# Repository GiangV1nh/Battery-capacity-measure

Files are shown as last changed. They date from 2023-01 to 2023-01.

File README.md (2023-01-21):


# 1. Giới thiệu
Mạch này đo dung lượng một cell Li-Ion hoặc nhiều cell Li-Ion mắc song song hoặc các loại pin khác có điện áp tối đa dưới 5.5V. Đơn vị dung lượng đo được là mAh.
# 2. Thông số kỹ thuật
- Điện áp nguồn cấp: 9V đến 15V.
- Điện áp pin đo được: 0V đến 5.5V.
- Dòng xả tối đa: 2A.
- Mức điều chỉnh dòng xả tối thiểu: 0.02A.
- EODV: 0V đến 4.2V.
- Mức điều chỉnh EODV tối thiểu: 0.02V.
- Dung lượng tối đa đo đươc: 99,999mAh.
# 3. Hướng dẫn sử dụng
Giao diện hiện thị trên LCD như sau:
|Hình 1 |
| :---: |
| |

Dòng xả và EODV là hai thông số điều chỉnh được. Bên cạnh có dấu *, biểu thị hiện đang điều chỉnh thông số nào. Dấu * ở vị trí nào thì khi vặn encoder sẽ điều chỉnh thông số tại vị trí đó. Để thay đổi vị trí dấu * thì nhấn nhả encoder. Điện áp pin là điện
áp đo được từ pin đang gắn vào mạch. Dung lượng pin tăng dần trong quá trình xác định. Sau khi đặt các thông số dòng xả và EODV, nhấn và giữ encoder trong hai giây
thì mạch bắt đầu xả pin, dấu * biến mất và LED báo hiệu trên mạch sáng. Trong quá trình xả, nhấn nhả encoder thì ngưng xả.

Chuẩn bị cell pin cần đo dung lượng, nạp đầy cell này và lắp vào mạch theo đúng cực tính. Không được lắp ngược lại vì làm cho diode trong MOSFET dẫn, có dòng xả lớn qua mạch gây hỏng. Tiến hành đặt dòng xả và áp EODV, sau đó nhấn và giữ encoder trong hai giây, dấu * biến mất và LED D1 sáng, báo hiệu đang xả pin. Trong quá trình xả, dung lượng pin hiển thị tăng dần. Khi điện áp pin xuống đến ngưỡng EODV, mạch ngưng xả, dung lượng pin được hiển thị trên LCD. Khi đo pin khác hoặc đo lại, cần phải reset mạch cho dung lượng hiển thị trên LCD bằng 0mAh.
Nếu không có pin (điện áp đo được 0V) hoặc điện áp pin thấp hơn hoặc bằng EODV hoặc dòng xả là 0A thì mạch không xả. Trong quá trình xả pin, nếu ngắt pin ra thì mạch tự ngừng xả và ngừng xác định dung lượng.

# Lưu ý
- Không gắn pin ngược cực.
- Không xả pin dưới mức EODV của loại pin đang cần xác định vì như thế sẽ làm hỏng pin.
# 4. Cách chỉnh mạch cho lần đầu dùng
Chuẩn bị nguồn có khả năng cấp dòng lớn hơn 2A. Nếu điện áp nguồn nhỏ hơn 5.5V thì cắm J3 như hình sau:
|Hình 2 |
| :---: |
| |

Nếu lớn hơn 5.5V thì để J3 như hình sau:
|Hình 3 |
| :---: |
| |

Nối nguồn vào mạch đúng cực tính, nối tiếp một ampe kế, đặt dòng xả 2A và cho phép xả. Chỉnh VR1 sao cho dòng trên ampe kế là 2A. Vậy là mạch đã chỉnh xong. Đặt J3 trở lại như hình 2.

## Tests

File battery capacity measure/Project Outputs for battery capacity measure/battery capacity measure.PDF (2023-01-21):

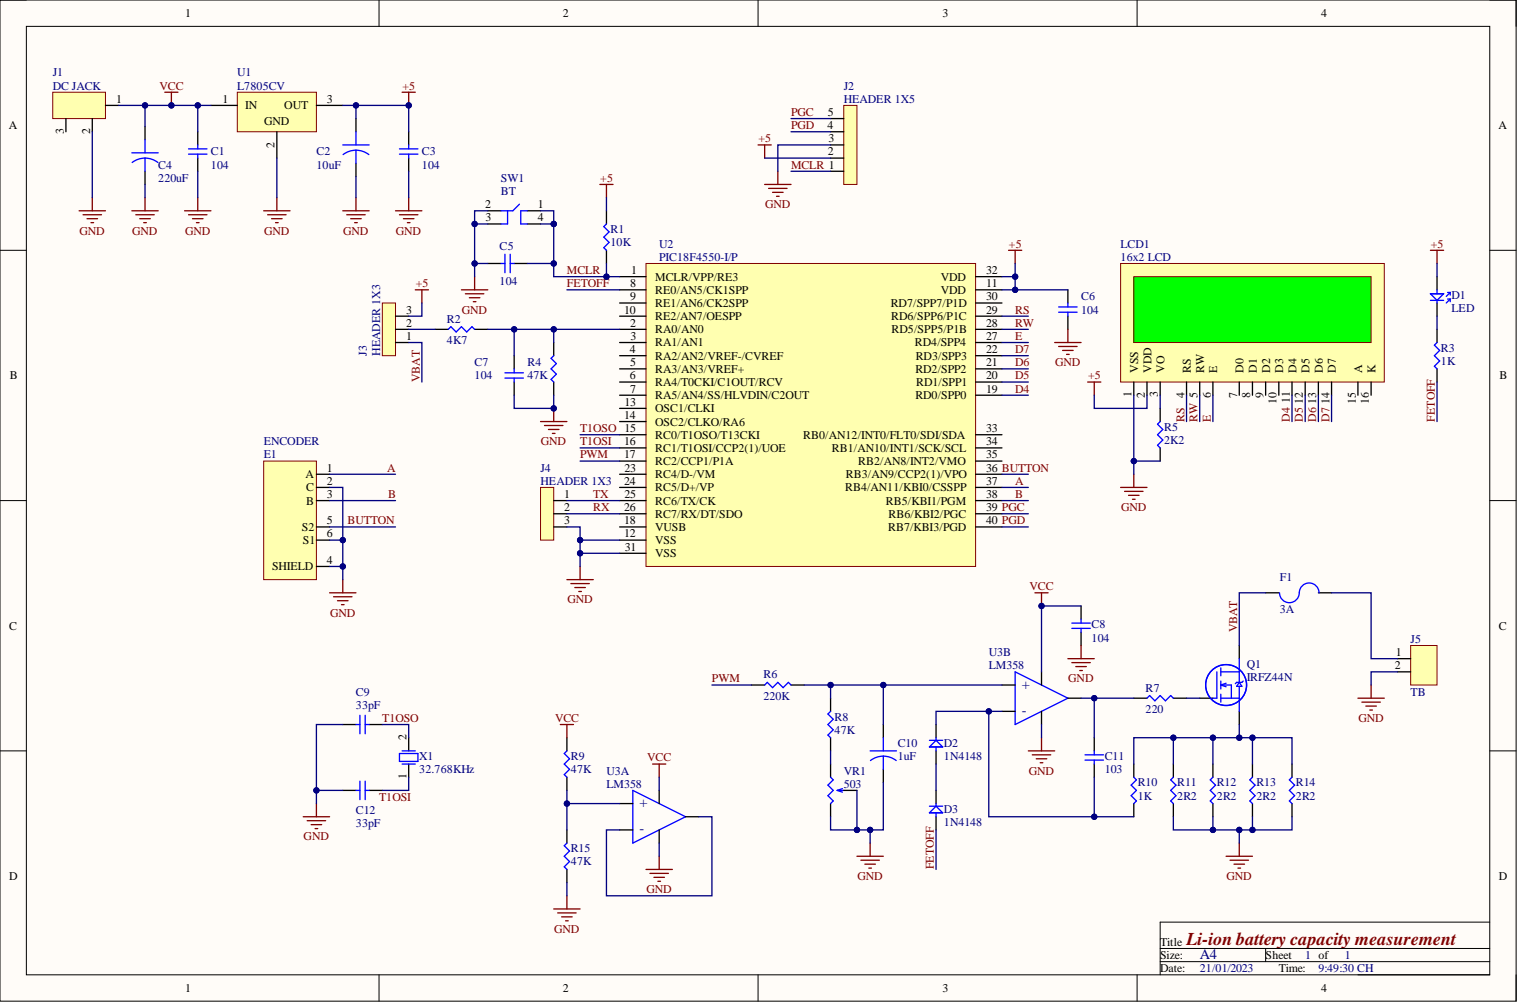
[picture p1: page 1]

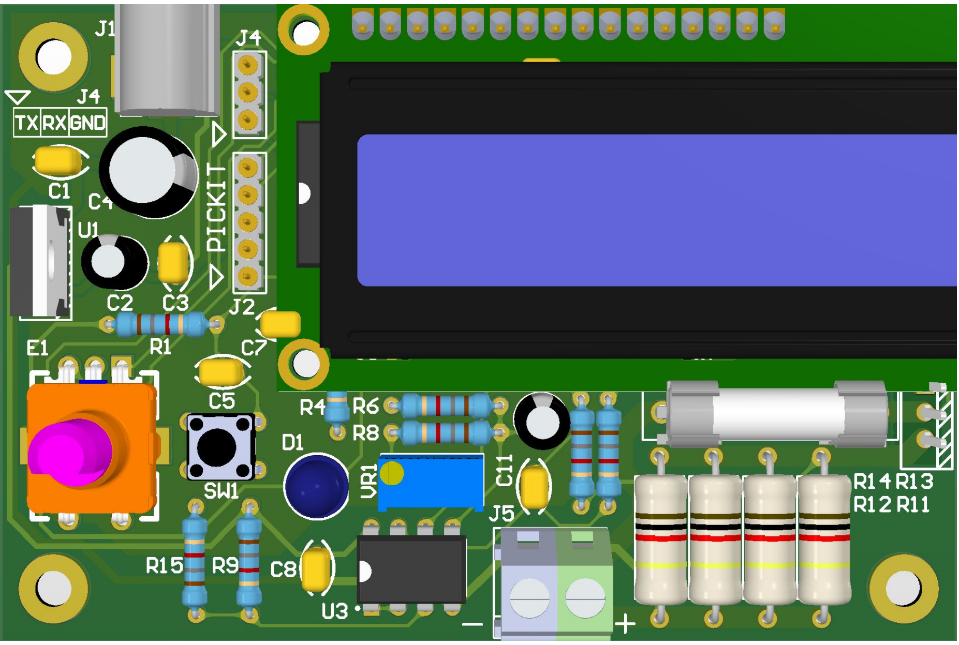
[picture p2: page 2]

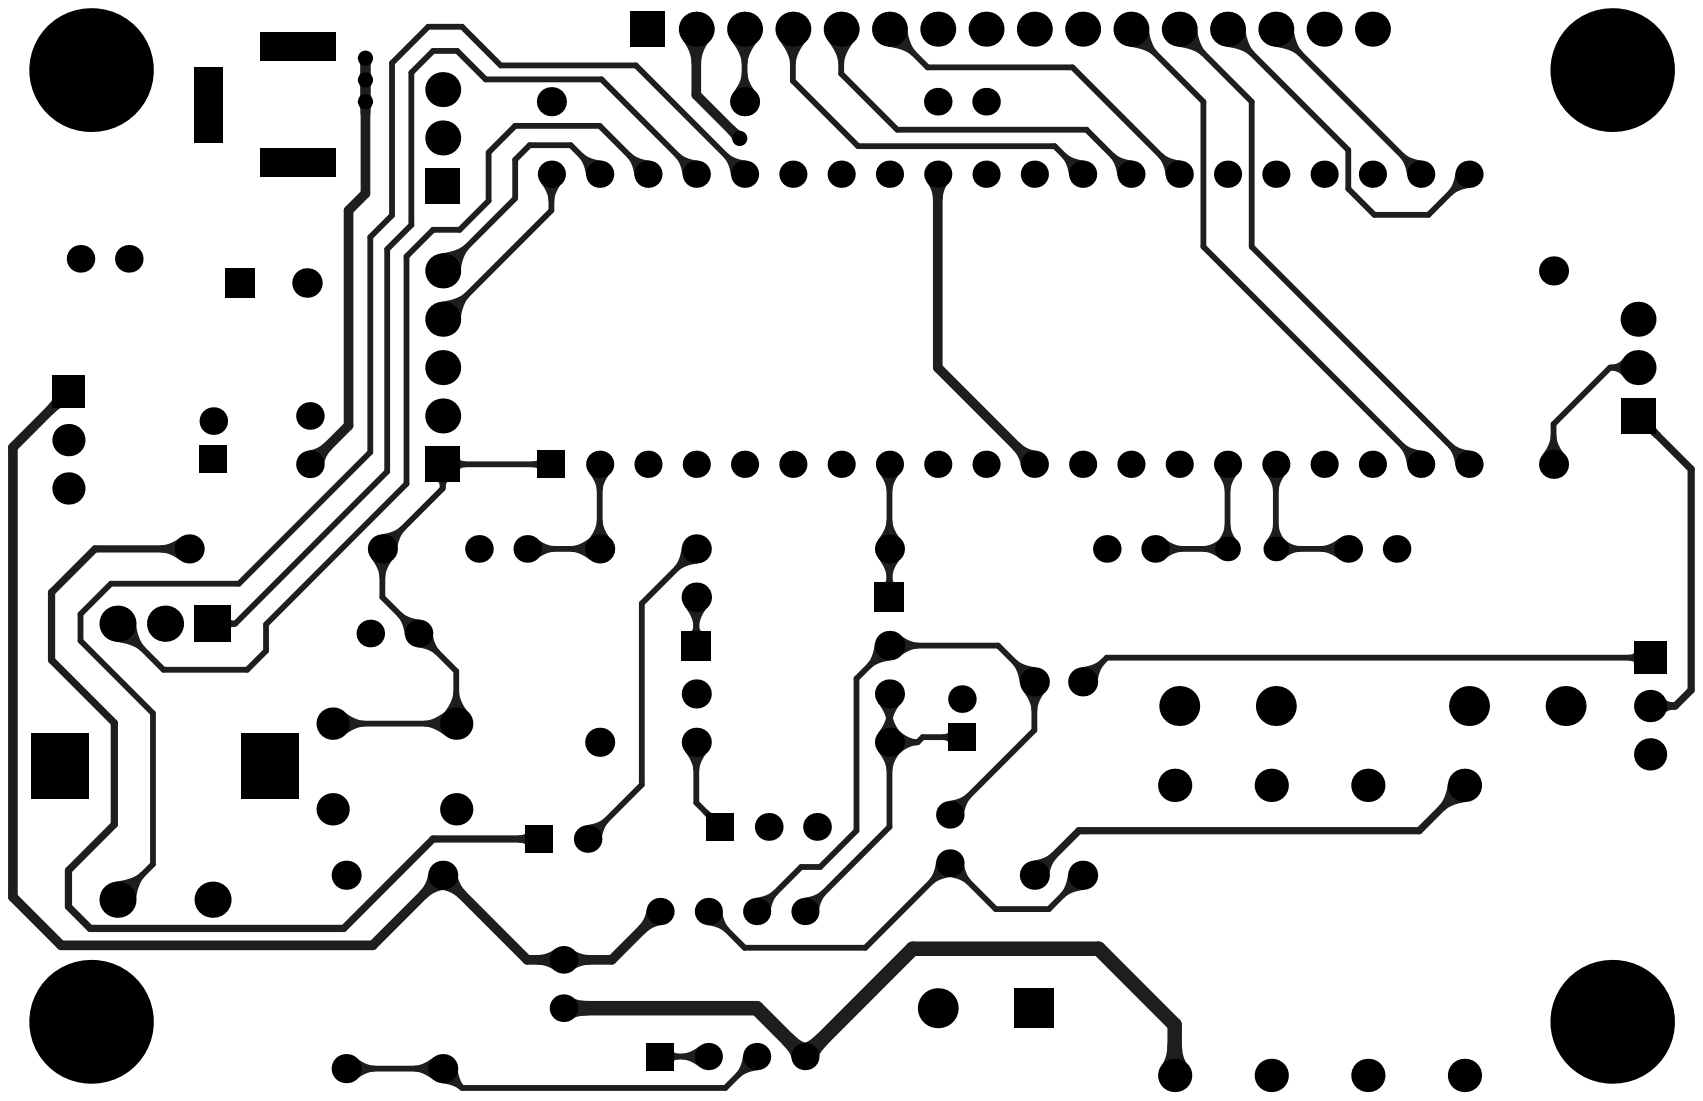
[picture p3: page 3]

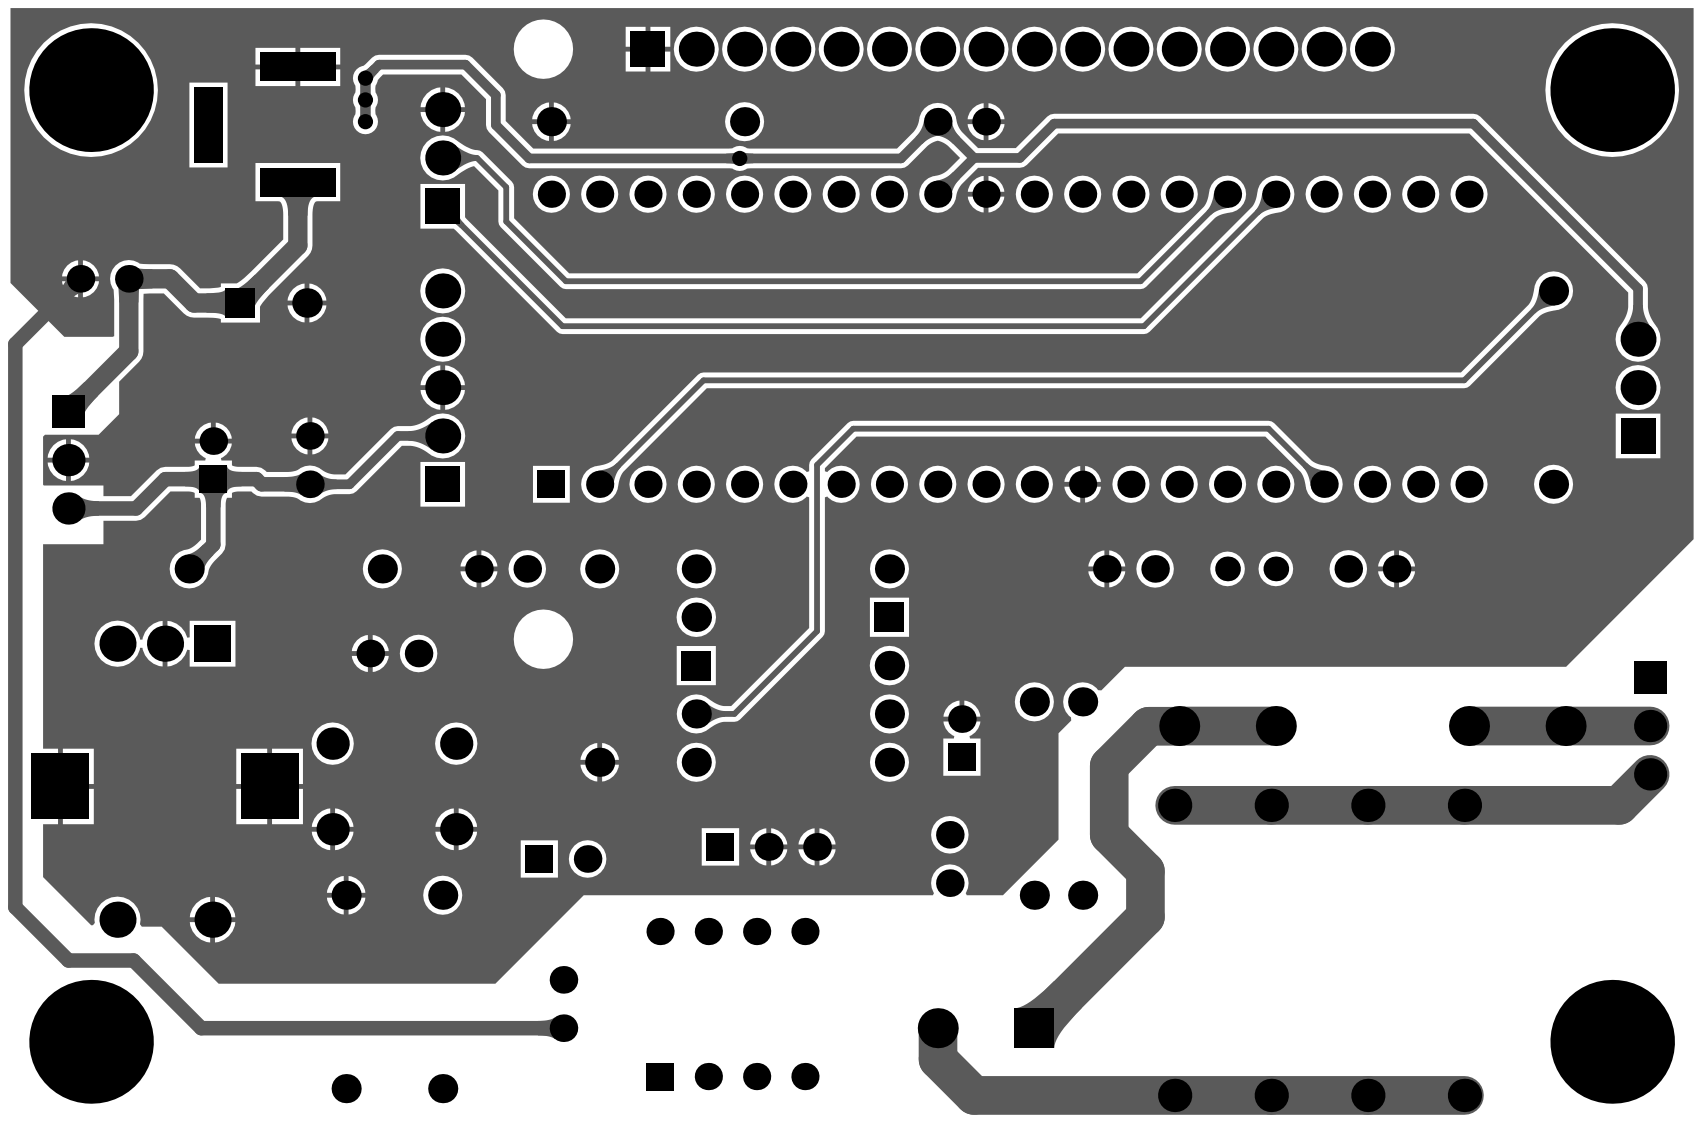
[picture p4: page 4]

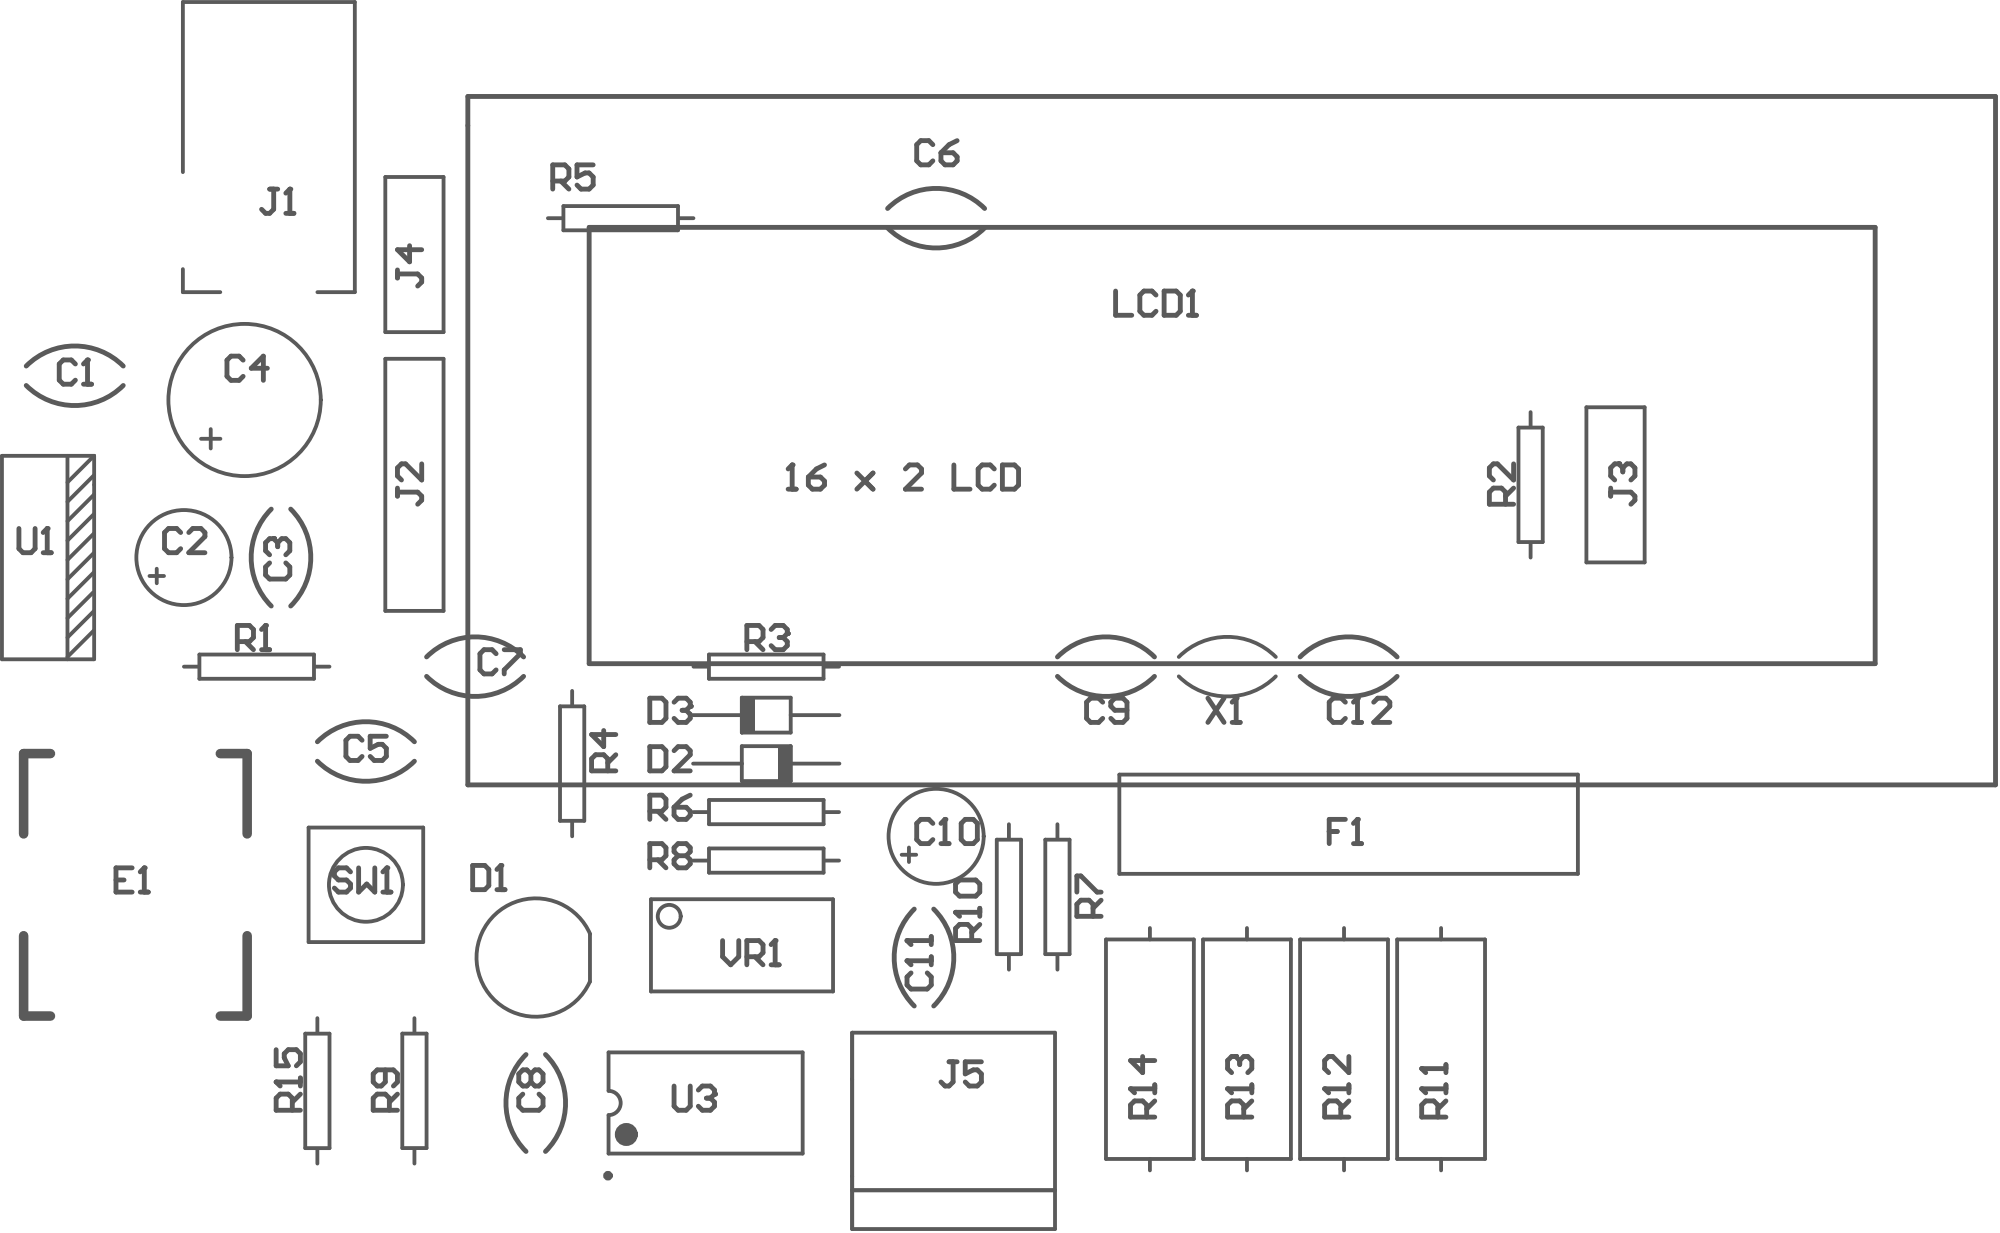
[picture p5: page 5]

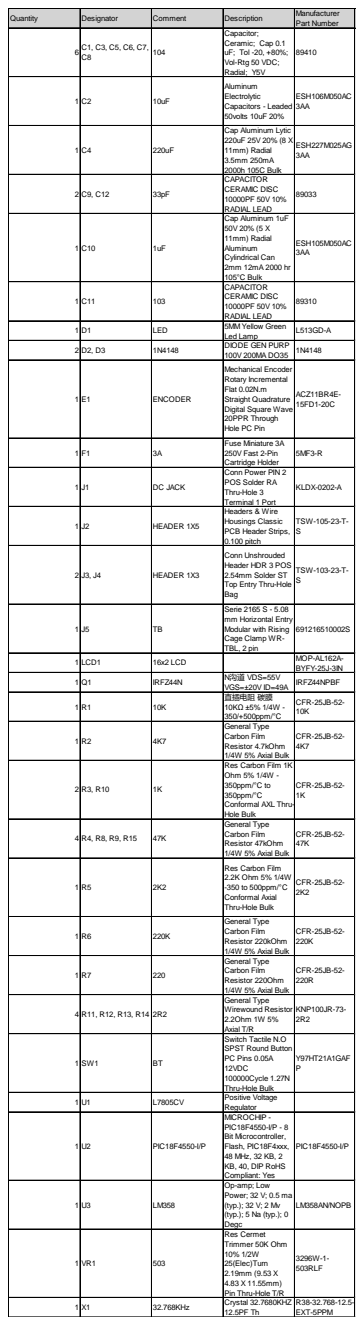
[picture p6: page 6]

Quantity | Designator | Comment | Description | Manufacturer Part Number

6 | C1, C3, C5, C6, C7, C8 | 104 | Capacitor; Ceramic; Cap 0.1 uF; Tol -20, +80%; Vol-Rtg 50 VDC; Radial; Y5V | 89410

1 | C2 | 10uF | Aluminum Electrolytic Capacitors - Leaded 50volts 10uF 20% | ESH106M050AC 3AA

1 | C4 | 220uF | Cap Aluminum Lytic 220uF 25V 20% (8 X 11mm) Radial 3.5mm 250mA 2000h 105C Bulk | ESH227M025AG 3AA

2 | C9, C12 | 33pF | CAPACITOR CERAMIC DISC 10000PF 50V 10% RADIAL LEAD | 89033

1 | C10 | 1uF | Cap Aluminum 1uF 50V 20% (5 X 11mm) Radial Aluminum Cylindrical Can 2mm 12mA 2000 hr 105°C Bulk | ESH105M050AC 3AA

1 | C11 | 103 | CAPACITOR CERAMIC DISC 10000PF 50V 10% RADIAL LEAD | 89310

1 | D1 | LED | 5MM Yellow Green Led Lamp | L513GD-A

2 | D2, D3 | 1N4148 | DIODE GEN PURP 100V 200MA DO35 | 1N4148

1 | E1 | ENCODER | Mechanical Encoder Rotary Incremental Flat 0.02N.m Straight Quadrature Digital Square Wave 20PPR Through Hole PC Pin | ACZ11BR4E-15FD1-20C

1 | F1 | 3A | Fuse Miniature 3A 250V Fast 2-Pin Cartridge Holder | 5MF3-R

1 | J1 | DC JACK | Conn Power PIN 2 POS Solder RA Thru-Hole 3 Terminal 1 Port | KLDX-0202-A

1 | J2 | HEADER 1X5 | Headers & Wire Housings Classic PCB Header Strips, 0.100 pitch | TSW-105-23-T-S

2 | J3, J4 | HEADER 1X3 | Conn Unshrouded Header HDR 3 POS 2.54mm Solder ST Top Entry Thru-Hole Bag | TSW-103-23-T-S

1 | J5 | TB | Serie 2165 S - 5.08 mm Horizontal Entry Modular with Rising Cage Clamp WR-TBL, 2 pin | 691216510002S

1 | LCD1 | 16x2 LCD | | MOP-AL162A-BYFY-25J-3IN

1 | Q1 | IRFZ44N | N沟道 VDS=55V VGS=±20V ID=49A | IRFZ44NPBF

1 | R1 | 10K | 直插电阻 碳膜 10KΩ ±5% 1/4W -350/+500ppm/°C | CFR-25JB-52-10K

1 | R2 | 4K7 | General Type Carbon Film Resistor 4.7kOhm 1/4W 5% Axial Bulk | CFR-25JB-52-4K7

2 | R3, R10 | 1K | Res Carbon Film 1K Ohm 5% 1/4W -350ppm/°C to 350ppm/°C Conformal AXL Thru-Hole Bulk | CFR-25JB-52-1K

4 | R4, R8, R9, R15 | 47K | General Type Carbon Film Resistor 47kOhm 1/4W 5% Axial Bulk | CFR-25JB-52-47K

1 | R5 | 2K2 | Res Carbon Film 2.2K Ohm 5% 1/4W -350 to 500ppm/°C Conformal Axial Thru-Hole Bulk | CFR-25JB-52-2K2

1 | R6 | 220K | General Type Carbon Film Resistor 220kOhm 1/4W 5% Axial Bulk | CFR-25JB-52-220K

1 | R7 | 220 | General Type Carbon Film Resistor 220Ohm 1/4W 5% Axial Bulk | CFR-25JB-52-220R

4 | R11, R12, R13, R14 | 2R2 | General Type Wirewound Resistor 2.2Ohm 1W 5% Axial T/R | KNP100JR-73-2R2

1 | SW1 | BT | Switch Tactile N.O SPST Round Button PC Pins 0.05A 12VDC 100000Cycle 1.27N Thru-Hole Bulk | Y97HT21A1GAF P

1 | U1 | L7805CV | Positive Voltage Regulator

1 | U2 | PIC18F4550-I/P | MICROCHIP -PIC18F4550-I/P - 8 Bit Microcontroller, Flash, PIC18F4xxx, 48 MHz, 32 KB, 2 KB, 40, DIP RoHS Compliant: Yes | PIC18F4550-I/P

1 | U3 | LM358 | Op-amp; Low Power; 32 V; 0.5 ma (typ.); 32 V; 2 Mv (typ.); 5 Na (typ.); 0 Degc | LM358AN/NOPB

1 | VR1 | 503 | Res Cermet Trimmer 50K Ohm 10% 1/2W 25(Elec)Turn 2.19mm (9.53 X 4.83 X 11.55mm) Pin Thru-Hole T/R | 3296W-1-503RLF

1 | X1 | 32.768KHz | Crystal 32.7680KHZ 12.5PF Th | R38-32.768-12.5-EXT-5PPM

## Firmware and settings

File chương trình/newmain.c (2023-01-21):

// PIC18F4550 Configuration Bit Settings

// 'C' source line config statements

#include <p18F4550.h>
#include <xlcd_portd.h>
#include <delays.h>
#include <math.h>
#include <stdio.h>

typedef enum {
    false, true
} bool;
#define BUTTON PORTBbits.RB3
#define BUTTONPIN TRISBbits.TRISB3
#define DISCHARGELED PORTEbits.RE0
#define DISCHARGELEDPIN TRISEbits.TRISE0
#define ENCODERAPIN TRISBbits.TRISB5
#define ENCODERBPIN TRISBbits.TRISB4
#define ENCODERINTIF INTCONbits.RBIF
#define PWMVALLOADDR 0x00
#define PWMVALHIADDR 0x01
#define CURRENTVALADDR 0x02
#define VOLVALLOADDR 0x03
#define VOLVALHIADDR 0x04
#define R_START 0x0  
#define R_CW_FINAL 0x1
#define R_CW_BEGIN 0x2
#define R_CW_NEXT 0x3
#define R_CCW_BEGIN 0x4
#define R_CCW_FINAL 0x5
#define R_CCW_NEXT 0x6
//0b00000100
#define DIR_CW 0x10
#define DIR_CCW 0x20
// CONFIG1L
#pragma config PLLDIV = 1       // PLL Prescaler Selection bits (No prescale (4 MHz oscillator input drives PLL directly))
#pragma config CPUDIV = OSC1_PLL2// System Clock Postscaler Selection bits ([Primary Oscillator Src: /1][96 MHz PLL Src: /2])
#pragma config USBDIV = 1       // USB Clock Selection bit (used in Full-Speed USB mode only; UCFG:FSEN = 1) (USB clock source comes directly from the primary oscillator block with no postscale)

// CONFIG1H
#pragma config FOSC = INTOSC_HS // Oscillator Selection bits (Internal oscillator, HS oscillator used by USB (INTHS))
#pragma config FCMEN = OFF      // Fail-Safe Clock Monitor Enable bit (Fail-Safe Clock Monitor disabled)
#pragma config IESO = OFF       // Internal/External Oscillator Switchover bit (Oscillator Switchover mode disabled)

// CONFIG2L
#pragma config PWRT = ON        // Power-up Timer Enable bit (PWRT enabled)
#pragma config BOR = ON         // Brown-out Reset Enable bits (Brown-out Reset enabled in hardware only (SBOREN is disabled))
#pragma config BORV = 3         // Brown-out Reset Voltage bits (Minimum setting)
#pragma config VREGEN = OFF     // USB Voltage Regulator Enable bit (USB voltage regulator disabled)

// CONFIG2H
#pragma config WDT = OFF        // Watchdog Timer Enable bit (WDT disabled (control is placed on the SWDTEN bit))
#pragma config WDTPS = 32768    // Watchdog Timer Postscale Select bits (1:32768)

// CONFIG3H
#pragma config CCP2MX = ON      // CCP2 MUX bit (CCP2 input/output is multiplexed with RC1)
#pragma config PBADEN = OFF     // PORTB A/D Enable bit (PORTB<4:0> pins are configured as digital I/O on Reset)
#pragma config LPT1OSC = OFF    // Low-Power Timer 1 Oscillator Enable bit (Timer1 configured for higher power operation)
#pragma config MCLRE = ON       // MCLR Pin Enable bit (MCLR pin enabled; RE3 input pin disabled)

// CONFIG4L
#pragma config STVREN = ON      // Stack Full/Underflow Reset Enable bit (Stack full/underflow will cause Reset)
#pragma config LVP = OFF         // Single-Supply ICSP Enable bit (Single-Supply ICSP enabled)
#pragma config ICPRT = OFF      // Dedicated In-Circuit Debug/Programming Port (ICPORT) Enable bit (ICPORT disabled)
#pragma config XINST = OFF      // Extended Instruction Set Enable bit (Instruction set extension and Indexed Addressing mode disabled (Legacy mode))

// CONFIG5L
#pragma config CP0 = OFF        // Code Protection bit (Block 0 (000800-001FFFh) is not code-protected)
#pragma config CP1 = OFF        // Code Protection bit (Block 1 (002000-003FFFh) is not code-protected)
#pragma config CP2 = OFF        // Code Protection bit (Block 2 (004000-005FFFh) is not code-protected)
#pragma config CP3 = OFF        // Code Protection bit (Block 3 (006000-007FFFh) is not code-protected)

// CONFIG5H
#pragma config CPB = OFF        // Boot Block Code Protection bit (Boot block (000000-0007FFh) is not code-protected)
#pragma config CPD = OFF        // Data EEPROM Code Protection bit (Data EEPROM is not code-protected)

// CONFIG6L
#pragma config WRT0 = OFF       // Write Protection bit (Block 0 (000800-001FFFh) is not write-protected)
#pragma config WRT1 = OFF       // Write Protection bit (Block 1 (002000-003FFFh) is not write-protected)
#pragma config WRT2 = OFF       // Write Protection bit (Block 2 (004000-005FFFh) is not write-protected)
#pragma config WRT3 = OFF       // Write Protection bit (Block 3 (006000-007FFFh) is not write-protected)

// CONFIG6H
#pragma config WRTC = OFF       // Configuration Register Write Protection bit (Configuration registers (300000-3000FFh) are not write-protected)
#pragma config WRTB = OFF       // Boot Block Write Protection bit (Boot block (000000-0007FFh) is not write-protected)
#pragma config WRTD = OFF       // Data EEPROM Write Protection bit (Data EEPROM is not write-protected)

// CONFIG7L
#pragma config EBTR0 = OFF      // Table Read Protection bit (Block 0 (000800-001FFFh) is not protected from table reads executed in other blocks)
#pragma config EBTR1 = OFF      // Table Read Protection bit (Block 1 (002000-003FFFh) is not protected from table reads executed in other blocks)
#pragma config EBTR2 = OFF      // Table Read Protection bit (Block 2 (004000-005FFFh) is not protected from table reads executed in other blocks)
#pragma config EBTR3 = OFF      // Table Read Protection bit (Block 3 (006000-007FFFh) is not protected from table reads executed in other blocks)

// CONFIG7H
#pragma config EBTRB = OFF      // Boot Block Table Read Protection bit (Boot block (000000-0007FFh) is not protected from table reads executed in other blocks)
unsigned int SetPWM = 0;
unsigned char SetCurrent = 0;
unsigned int SetVoltage = 0;
unsigned char State = 0;
unsigned long Second = 0;
const unsigned char ttable[7][4] = {
    // R_START
    {R_START, R_CW_BEGIN, R_CCW_BEGIN, R_START},
    // R_CW_FINAL
    {R_CW_NEXT, R_START, R_CW_FINAL, R_START | DIR_CW},
    // R_CW_BEGIN
    {R_CW_NEXT, R_CW_BEGIN, R_START, R_START},
    // R_CW_NEXT
    {R_CW_NEXT, R_CW_BEGIN, R_CW_FINAL, R_START},
    // R_CCW_BEGIN
    {R_CCW_NEXT, R_START, R_CCW_BEGIN, R_START},
    // R_CCW_FINAL
    {R_CCW_NEXT, R_CCW_FINAL, R_START, R_START | DIR_CCW},
    // R_CCW_NEXT
    {R_CCW_NEXT, R_CCW_FINAL, R_CCW_BEGIN, R_START},
};
unsigned char count = 0;
unsigned char PinState = 0;
unsigned char Dir = 0;
unsigned char S = 0;
void LCDInit(void);
void DelayFor18TCY(void); //Delay 18TCY
void DelayPORXLCD(void); //Delay 15ms
void DelayXLCD(void);
void ftostr(float, unsigned char*, unsigned char);
void inttostr(int, char, unsigned char*, unsigned char);
int intToStr(int, char[], int);
void DisplayStarEnDis(bool);
void SetCurrentDisplay(unsigned char);
void SetVoltageDisplay(unsigned int);
void DisplayCapacity(unsigned int);
void BatteryVoltageDisplay(unsigned long);
void ChangePWM(unsigned int);
void CCPInit(void);
void InterruptInit(void);
void EncoderInterruptInit(void);
void Timer0Init(void);
void Timer1Init(void);
void ADCInit(void);
unsigned long BatteryVoltageMeasure(void);
void IsCurrent(void);
void Timer1EnDis(bool);
void EncoderInterruptISR(void);
void Timer1InterruptISR(void);
void EncoderEnDis(bool);
void PWMEnDis(bool);
bool DebonceButton(void);
void EEPROMAccess(void);
void EEPROMWrite(unsigned char, unsigned char);
unsigned char EEPROMRead(unsigned char);

void main() {
    bool Pushed = false;
    bool Hold = false;
    bool PrevHold = false;
    unsigned char case2 = 0;
    unsigned char prevState = 0;
    unsigned char PrevSetCurrent = 0;
    unsigned char PrevSetCurrent1 = 0;
    unsigned char PrevSetVoltage = 0;
    unsigned int PrevSetPWM = 0;
    unsigned int SetPWMEEPROM = 0;
    unsigned char SetCurrentEEPROM = 0;
    unsigned int SetVoltageEEPROM = 0;
    unsigned long BatVoltage = 0;
    unsigned int Capacity = 0;
    unsigned int PrevCapacity = 0;
    char strBatVoltage[3];
    OSCCON = 0x72; //Chon tan so dao dong noi la 8Mhz, nguon xung clock tu dao dong noi
    BUTTONPIN = 1;
    DISCHARGELEDPIN = 0;
    DISCHARGELED = 1;
    INTCON2bits.RBPU = 0; //Dung dien tro keo len cho PORTB
    EncoderInterruptInit();
    InterruptInit();
    Timer0Init();
    Timer1Init();
    CCPInit();
    ADCInit();
    EEPROMAccess();
    SetPWMEEPROM = EEPROMRead(PWMVALHIADDR);
    SetPWMEEPROM = (SetPWMEEPROM << 8) | EEPROMRead(PWMVALLOADDR);
    SetCurrentEEPROM = EEPROMRead(CURRENTVALADDR);
    SetVoltageEEPROM = EEPROMRead(VOLVALHIADDR);
    SetVoltageEEPROM = (SetVoltageEEPROM << 8) | EEPROMRead(VOLVALLOADDR);
    if (SetPWMEEPROM > 800 || SetCurrentEEPROM > 200 || SetVoltageEEPROM > 420) {
        SetPWM = 0;
        SetCurrent = 0;
        SetVoltage = 0;
   } else {
        SetPWM = SetPWMEEPROM;
        SetCurrent = SetCurrentEEPROM;
        SetVoltage = SetVoltageEEPROM;
    }
    LCDInit();
    DisplayStarEnDis(true);
    SetCurrentDisplay(SetCurrent);
    SetVoltageDisplay(SetVoltage);
    while (1) {
        BatVoltage = BatteryVoltageMeasure();
        sprintf(strBatVoltage, "%lu%lu%lu", BatVoltage / 100000, (BatVoltage % 100000) / 10000, (BatVoltage % 10000) / 1000);
        if (DebonceButton() == true) {
            if (Pushed == false) {
                Pushed = true;
                TMR0H = 0x0B;
                TMR0L = 0xDC;
                INTCONbits.TMR0IF = 0;
                T0CONbits.TMR0ON = 1;
            }
            if (INTCONbits.TMR0IF == 1 && Hold == false) {
                Hold = true;
                PrevHold = true;
                State = 2;
                INTCONbits.TMR0IF = 0;
                T0CONbits.TMR0ON = 0;
            }
        } else {
            if (Pushed == true) {
                if (Hold == false) {
                    Pushed = false;
                    INTCONbits.TMR0IF = 0;
                    T0CONbits.TMR0ON = 0;
                    if (PrevHold == true) {
                        State = 0;
                        PrevHold = 0;
                    } else {
                        State++;
                        State = State % 2;
                    }
                } else {
                    Pushed = false;
                    Hold = false;
                }
            }
        }
        switch (State) {
            case 0:
                PORTCbits.RC2 = 0;
                PWMEnDis(false);
                Timer1EnDis(false);
                DISCHARGELED = 1;
                EncoderEnDis(true);
                ChangePWM(SetPWM);
                case2 = 0;
                break;
            case 1:
                PWMEnDis(false);
                Timer1EnDis(false);
                DISCHARGELED = 1;
                EncoderEnDis(true);
                case2 = 0;
                break;
            case 2:
                if (atoi(strBatVoltage) > 0 && atoi(strBatVoltage) > SetVoltage && SetCurrent != 0) {
                    if (case2 == 0) {
                        DisplayStarEnDis(false);
                        EncoderEnDis(false);
                        DISCHARGELED = 0;
                        Timer1EnDis(true);
                        PWMEnDis(true);
                        if (PrevSetCurrent1 != SetCurrent) {
                            PrevSetCurrent1 = SetCurrent;
                            PrevCapacity = Capacity;
                            Second = 0;
                        }
                        case2 = 1;
                    }
                    Capacity = (((SetCurrent * Second) / 3600.0) * 10) + PrevCapacity;
                } else {
                    State = 0;
                    PrevHold = false;
                }
                break;
        }
        if (State != prevState) {
            prevState = State;
            DisplayStarEnDis(true);
        }
        if (PrevSetCurrent != SetCurrent || PrevSetPWM != SetPWM) {
            PrevSetCurrent = SetCurrent;
            PrevSetPWM = SetPWM;
            EEPROMWrite(PWMVALLOADDR, SetPWM);
            EEPROMWrite(PWMVALHIADDR, SetPWM >> 8);
            EEPROMWrite(CURRENTVALADDR, SetCurrent);
            SetCurrentDisplay(SetCurrent);
        }
        if (PrevSetVoltage != SetVoltage) {
            PrevSetVoltage = SetVoltage;
            EEPROMWrite(VOLVALLOADDR, SetVoltage);
            EEPROMWrite(VOLVALHIADDR, SetVoltage >> 8);
            SetVoltageDisplay(SetVoltage);
        }
        BatteryVoltageDisplay(BatVoltage);
        DisplayCapacity(Capacity);
    }
}

/*Phuong phap chong nhay nut nhan. Xem tai: http://www.ganssle.com/debouncing.htm*/
bool DebonceButton() {
    unsigned int State = 0;
    State = (State << 1) | BUTTON | 0xF000;
    if (State == 0xF000)
        return true;
    return false;
}
/*---------------------------------------------------------------------*/
#pragma code Timer1Interrupt = 0x08

void Timer1Interrupt() {
    _asm
            goto Timer1InterruptISR
            _endasm
}
#pragma code
#pragma interrupt Timer1InterruptISR

void Timer1InterruptISR() {
    if (PIR1bits.TMR1IF == 1) {
        Second++;
        PIR1bits.TMR1IF = 0;
        TMR1H = 0x80;
        TMR1L = 0x00;
    }
}
#pragma code EncoderInterrupt = 0x18

void EncoderInterrupt() {
    _asm
            goto EncoderInterruptISR
            _endasm
}
#pragma code
#pragma interruptlow EncoderInterruptISR

void EncoderInterruptISR() {
    if (ENCODERINTIF == 1) {
        ENCODERINTIF = 0;
        /*Phuong phap chong nhay encoder. Xem tai: http://www.buxtronix.net/2011/10/rotary-encoders-done-properly.html*/
        PinState = ((PORTBbits.RB4) << 1) | PORTBbits.RB5;
        S = ttable[S & 0xf][PinState];
        Dir = S & 0x30;
        /*-----------------------------------------------------------------------------------*/
        if (Dir == DIR_CW) {
            switch (State) {
                case 0:
                    if (SetPWM < 800 && SetCurrent < 200) {
                        SetPWM = SetPWM + 8;
                        SetCurrent = SetCurrent + 2;
                    }
                    break;
                case 1:
                    if (SetVoltage < 420) {
                        SetVoltage = SetVoltage + 2;
                    }
                    break;
            }
        }
        if (Dir == DIR_CCW) {
            switch (State) {
                case 0:
                    if (SetPWM > 0 && SetCurrent > 0) {
                        SetPWM = SetPWM - 8;
                        SetCurrent = SetCurrent - 2;
                    }
                    break;
                case 1:
                    if (SetVoltage > 0) {
                        SetVoltage = SetVoltage - 2;
                    }
                    break;
            }
        }
    }
}

void InterruptInit() {
    RCONbits.IPEN = 1;
    INTCONbits.PEIE = 1;
    INTCONbits.GIE = 1;
}

void ChangePWM(unsigned int PWMValue) {
    CCP1CONbits.DC1B = PWMValue & 0x03;
    CCPR1L = PWMValue >> 2;
}

void DelayFor18TCY() {
    char i;
    for (i = 0; i < 17; i++) {
        Delay1TCY();
    }
}

void DelayPORXLCD() {
    Delay1KTCYx(40);
}

void DelayXLCD() {
    Delay1KTCYx(30);
}

void EncoderInterruptInit() {
    ENCODERAPIN = 1;
    ENCODERBPIN = 1;
    ENCODERINTIF = 0; // Encoder dung ngat thay doi PORTB, bit co la RBIF
    INTCON2bits.RBIP = 0; // Ngat encoder co do uu tien thap
}

void LCDInit() {
    OpenXLCD(FOUR_BIT & LINES_5X7);
    while (BusyXLCD());
    WriteCmdXLCD(0x08); //Display/Cursor ON/OFF control: Display off, cursor off, blink off
    while (BusyXLCD());
    WriteCmdXLCD(0x01); //Clear Display
    while (BusyXLCD());
    WriteCmdXLCD(0x06); //Entry mode set: Shift cursor to right, no display shift
    while (BusyXLCD());
    WriteCmdXLCD(0x0C); //Display/Cursor ON/OFF control: Display on, cursor on, blink off
    while (BusyXLCD());
}

void CCPInit() {
    PR2 = 0xFF; // Chu ky PWM
    CCPR1L = 0x00;
    CCP1CON = 0x00; //Ngo ra PWM chi duy nhat chan RC2, khoi CCP tat
    TRISCbits.TRISC2 = 0; //RC2 la ngo ra
    T2CON = 0x00; //Timer 2 khong dung prescaler, tat Timer2
}

void Timer0Init() {//Timer0 dung de dem thoi gian nhan giu nut
    T0CON = 0b00000101; //Timer 0 hoat dong 16bit, dung nguon xung tu VDK, prescaler 1:64
    //INTCONbits.TMR0IF = 0;
    TMR0H = 0;
    TMR0L = 0;
}

void Timer1Init() {// Timer1 dung de dem thoi gian khi xa pin, cu 1 giay tao ngat
    T1CON = 0b10000110; //Xung clock VDK khong tu dao dong Timer1, prescaler 1:1, dao dong Timer1 tat, xung clock tu chan RC0
    IPR1bits.TMR1IP = 1; // Ngt Timer1 uu tien cao
    PIR1bits.TMR1IF = 0;
    TMR1H = 0x80; //Gia tri nap vao TMR1H:TMR1L de tran trong t giay la: TMR1H:TMR1L=(65536 - (t/(1/ftimer1)))
    TMR1L = 0x00; //t = 1s => TMR1H:TMR1L = 32768 = 0x8000
}

void EncoderEnDis(bool EnDis) {
    switch (EnDis) {
        case false:
            INTCONbits.RBIE = 0;
            break;
        case true:
            INTCONbits.RBIE = 1;
            break;
    }
}

void ADCInit() {
    ADCON1 = 0b00001110; // Vref+ = 5v, Vref- = 0v, AN0 la ngo vao tuong tu
    ADCON2 = 0b10010001; // Acqition time = 4Tad, AD clock Fosc/8
    ADCON0bits.ADON = 1; // Bat khoi ADC
}

unsigned long BatteryVoltageMeasure() {
    unsigned long BatteryVoltage = 0;
    ADCON0bits.GO = 1;
    while (ADCON0bits.GO == 1);
    BatteryVoltage = ADRES * (unsigned long) 538;
    return BatteryVoltage;
}

void PWMEnDis(bool EnDis) {
    switch (EnDis) {
        case false://Khi khong dung PWM thì tat khoi CCP và Timer2
            CCP1CONbits.CCP1M = 0; //Tat khoi CCP
            T2CONbits.TMR2ON = 0; //Tat Timer2
            break;
        case true://Bat PWM
            CCP1CONbits.CCP1M = 0b1100; //Che do PWM, chan RC2 tich cuc muc cao
            T2CONbits.TMR2ON = 1;
            break;
    }
}

void Timer1EnDis(bool EnDis) {
    switch (EnDis) {
        case false://Khi tat Timer1, tat luon ca ngat va nguon dao dong cua Timer1 
            T1CONbits.TMR1ON = 0;
            PIE1bits.TMR1IE = 0;
            T1CONbits.T1OSCEN = 0;
            break;
        case true:// Bat Timer1, nap lai gia tri cho TMR1H:TMR1L
            PIR1bits.TMR1IF = 0;
            TMR1H = 0x80;
            TMR1L = 0x00;
            T1CONbits.T1OSCEN = 1;
            T1CONbits.TMR1ON = 1;
            PIE1bits.TMR1IE = 1;
            break;
    }
}

void DisplayStarEnDis(bool EnDis) {
    switch (EnDis) {
        case false:
            SetDDRamAddr(0x80);
            while (BusyXLCD());
            putcXLCD(' ');
            while (BusyXLCD());
            SetDDRamAddr(0xC0);
            while (BusyXLCD());
            putcXLCD(' ');
            break;
        case true:
            switch (State) {
                case 0:
                    SetDDRamAddr(0xC0);
                    while (BusyXLCD());
                    putcXLCD(' ');
                    while (BusyXLCD());
                    SetDDRamAddr(0x80);
                    while (BusyXLCD());
                    putcXLCD('*');
                    break;
                case 1:
                    SetDDRamAddr(0x80);
                    while (BusyXLCD());
                    putcXLCD(' ');
                    while (BusyXLCD());
                    SetDDRamAddr(0xC0);
                    while (BusyXLCD());
                    putcXLCD('*');
                    break;
            }
            break;
    }
}

void EEPROMAccess() {
    EECON1bits.EEPGD = 0;
    EECON1bits.CFGS = 0;
}

void EEPROMWrite(unsigned char Address, unsigned char WriteValue) {
    EEADR = Address;
    EEDATA = WriteValue;
    EECON1bits.WREN = 1;
    EECON2 = 0x55;
    EECON2 = 0xAA;
    EECON1bits.WR = 1;
    while (EECON1bits.WR == 1);
    EECON1bits.WR = 0;
}

unsigned char EEPROMRead(unsigned char Address) {
    EEADR = Address;
    EECON1bits.RD = 1;
    while (EECON1bits.RD == 1);
    return (EEDATA);
}

void SetCurrentDisplay(unsigned char Current) {
    unsigned char strCurrent[7];
    sprintf(strCurrent, "%d.%d%dA", (int) Current / 100, (int) (Current % 100) / 10, (int) (Current % 100) % 10);
    SetDDRamAddr(0x81);
    while (BusyXLCD());
    putsXLCD(strCurrent);
}

void SetVoltageDisplay(unsigned int Voltage) {
    unsigned char strVoltage[7];
    sprintf(strVoltage, "%d.%d%dV", (int) Voltage / 100, (int) (Voltage % 100) / 10, (int) (Voltage % 100) % 10);
    SetDDRamAddr(0xC1);
    while (BusyXLCD());
    putsXLCD(strVoltage);
}

void BatteryVoltageDisplay(unsigned long BattVoltage) {
    unsigned char strBattVoltage[7];
    sprintf(strBattVoltage, "%lu.%lu%luV", BattVoltage / 100000, (BattVoltage % 100000) / 10000, (BattVoltage % 10000) / 1000);
    SetDDRamAddr(0x89);
    while (BusyXLCD());
    putsXLCD(strBattVoltage);
}

void DisplayCapacity(unsigned int Capacity) {
    unsigned char strCapacity[9];
    sprintf(strCapacity, "%d%d%d%d%dmAh", Capacity / 10000, (Capacity % 10000) / 1000, (Capacity % 1000) / 100, (Capacity % 100) / 10, Capacity % 10);
    SetDDRamAddr(0xC8);
    while (BusyXLCD());
    putsXLCD(strCapacity);
}

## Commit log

2022-04-29 Revert "a"
    This reverts commit 4a88cee1ba12bedd73a222112956c821754e2309.
    [SCH.SchDoc, battery capacity measure.PrjPcb]
2022-04-29 Revert "a"
    This reverts commit 6b54728ea7c7618bc76a3130a3b9b50095fdca45.
    [newmain.c]
2023-01-21 Cập nhật hình
2023-01-21 Cập nhật chương trình
2023-01-21 Cập nhật file mạch
    [SCH.SchDoc, battery capacity measure.PrjPcb]
2023-01-21 Cập nhật file Gerber
    [PCB.GBL, PCB.GBO, PCB.GBP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]
2023-01-21 Cập nhật file NC Drill
2023-01-21 Cập nhật readme
